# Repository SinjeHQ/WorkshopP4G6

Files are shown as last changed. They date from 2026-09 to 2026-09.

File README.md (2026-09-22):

# Sentinel — Sas de sécurité autonome du vaisseau

Projet réalisé pour le **Workshop National EPSI B3 — "Horizon 2080"** (septembre 2026), Pilier 4.

## L'idée en une phrase

On simule le sas d'entrée d'un vaisseau spatial qui doit rester sécurisé même quand il n'a plus aucun contact avec la Terre : un badge ouvre la porte, un capteur surveille qu'elle ne s'ouvre pas sans autorisation, et tout continue de fonctionner même si le réseau est coupé.

## Contexte du sujet

En 2080, l'ESA envoie des vaisseaux autonomes explorer l'espace lointain. Ces vaisseaux ne peuvent plus communiquer en temps réel avec la Terre, donc ils doivent savoir se protéger et fonctionner tout seuls. Notre projet répond à ça avec un système de sécurité physique complet.

## Composition de l'équipe

- **2 développeurs**
- **3 infra/réseau**

## Le projet est découpé en 4 parties

### 1. La partie IoT (l'objet physique)

C'est le cœur du projet : une carte électronique (ESP8266) qui pilote un mini "sas" physique.

- Un **lecteur de badge** identifie qui essaie de passer
- Une **porte motorisée** (petit servo-moteur) s'ouvre ou reste fermée selon le badge
- Un **capteur** surveille si la porte s'ouvre sans autorisation
- Une **alarme sonore et lumineuse** se déclenche en cas de problème

Quatre équipes du vaisseau ont chacune leur badge :

| Équipe | Accès au sas |
|---|---|
| Équipe Sécurité | ✅ Autorisé |
| Équipe Médicale | ✅ Autorisé |
| Équipe Énergétique | ❌ Refusé |
| Équipe Alimentaire | ❌ Refusé |

**Ce qui se passe concrètement :**
- Bon badge d'une équipe autorisée → petit bip, lumière verte, la porte s'ouvre puis se referme toute seule après 3 secondes
- Mauvais badge ou équipe non autorisée → lumière rouge, bip d'alerte
- Quelqu'un force la porte sans badge → alarme continue (son + lumière rouge clignotante) qui ne s'arrête que si un badge autorisé est présenté, peu importe si la porte est encore ouverte ou non

### 2. Le dashboard (l'écran de contrôle)

Une interface web qui permet de suivre en direct ce qui se passe sur le sas : qui est passé, quand, si une alarme a été déclenchée, et si le lien avec la Terre est actif ou coupé.

### 3. Le réseau sécurisé (la partie infra)

On simule le réseau interne du vaisseau avec plusieurs machines virtuelles :
- Une machine qui joue le rôle de **passerelle vers la Terre**, qu'on peut couper à volonté pour simuler une panne de communication
- Une machine qui fait tourner le réseau interne du vaisseau (réception des données du badge, surveillance, tableaux de bord)
- Un système qui **repère un comportement suspect** sur le réseau et isole automatiquement l'appareil concerné

L'objectif : montrer que même sans la Terre, le vaisseau continue à se défendre et à fonctionner tout seul.

### 4. La maquette 3D

Une représentation physique du sas (porte, cadre) sur laquelle sont fixés les composants électroniques (badge, capteur, moteur, alarme), pour rendre la démonstration concrète et visuelle devant le jury.

## Matériel utilisé (partie IoT)

| Composant | Rôle |
|---|---|
| ESP8266 (NodeMCU) | Cerveau électronique du système |
| Lecteur RFID RC522 | Lit les badges |
| Micro-servo SG90 | Ouvre/ferme la porte |
| Buzzer | Son d'alerte |
| Capteur magnétique | Détecte si la porte est ouverte ou fermée |
| LED rouge | Voyant d'alerte |
| LED verte | Voyant d'accès autorisé |

## Câblage

| Composant | Branché sur |
|---|---|
| Lecteur de badge | broches 3V, D3, G, D6, D7, D5, D8 |
| Moteur de la porte | broche D2 |
| Buzzer | broche D1 |
| Capteur de porte | broches 3V, G, A0 |
| Voyant rouge | broche D4 |
| Voyant vert | broche D0 |

**Attention alimentation** : pendant les tests, la carte doit être alimentée uniquement par le câble USB de l'ordinateur — jamais avec le bloc d'alimentation externe en même temps, pour ne pas l'endommager.

## Scénario de démonstration

1. On montre le fonctionnement normal : un badge autorisé ouvre la porte sans problème
2. On coupe volontairement le lien avec la Terre → le sas continue de fonctionner tout seul
3. On force la porte sans badge → l'alarme se déclenche immédiatement
4. On présente un badge autorisé → l'alarme s'arrête
5. On rétablit le lien avec la Terre → tout se resynchronise sur le dashboard

## Pistes d'amélioration pour une future version

- Garder un historique de tous les passages avec la date et l'heure
- Sécuriser davantage les échanges de données entre le sas et le dashboard
- Gérer plusieurs sas en même temps sur le même vaisseau

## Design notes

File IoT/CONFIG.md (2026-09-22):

# Initialiser `IoT.ino` avec Arduino IDE et NodeMCU 1.0

## Prérequis

- Installer Arduino IDE.
- Connecter la carte **NodeMCU 1.0 (ESP-12E Module)** au PC avec un câble USB permettant le transfert de données.
- Ouvrir le fichier `IoT.ino` dans Arduino IDE.

## Installer le support ESP8266

1. Ouvrir **Fichier > Préférences**.
2. Dans **URL de gestionnaire de cartes supplémentaires**, ajouter :
	`https://arduino.esp8266.com/stable/package_esp8266com_index.json`
3. Aller dans **Outils > Type de carte > Gestionnaire de cartes**.
4. Rechercher `ESP8266` et installer **esp8266 by ESP8266 Community**.

## Sélectionner la carte et le COM

1. Aller dans **Outils > Type de carte > ESP8266 Boards > NodeMCU 1.0 (ESP-12E Module)**.
2. Aller dans **Outils > Port** et sélectionner le port **COM** correspondant à la carte (par exemple `COM3`).
3. Si aucun port n’apparaît, installer le pilote USB adapté à la puce de la carte (CH340 ou CP210x), reconnecter la carte et redémarrer Arduino IDE.

## Téléverser le programme

1. Vérifier que le fichier principal s’appelle `IoT.ino` et que les éventuelles bibliothèques requises sont installées via **Outils > Gérer les bibliothèques**.
2. Cliquer sur **Vérifier** pour compiler.
3. Cliquer sur **Téléverser**.
4. Attendre le message **Téléversement terminé**. Si nécessaire, maintenir le bouton **FLASH** pendant le début du téléversement, puis le relâcher.
5. Ouvrir **Outils > Moniteur série** et sélectionner le débit indiqué dans le code (`Serial.begin(...)`).

Après chaque reconnexion, vérifier que le bon port COM est sélectionné avant de téléverser.

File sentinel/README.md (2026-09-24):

# Sentinel

Projet Workshop EPSI - Horizon 2080.

## Infrastructure

La V1 de l'infrastructure utilise :

- Debian Linux
- Docker
- Mosquitto MQTT
- Python
- PostgreSQL
- Grafana

## Architecture

```text
ESP8266
   |
   | MQTT
   v
Mosquitto
   |
   v
Python MQTT Listener
   |
   v
PostgreSQL
   |
   v
Grafana

<img width="1513" height="757" alt="SENTINEL_Architecture_V3 drawio" src="https://github.com/user-attachments/assets/c140471f-d6b1-40b4-9b26-e571d9b06512" />

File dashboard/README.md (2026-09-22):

# Sentinel — console du sas

Dashboard React du groupe 6, Workshop Horizon 2080.

Il affiche quatre choses, rafraîchies toutes les 3 secondes :

1. l'état du sas, d'après le dernier événement reçu ;
2. le lien avec la Terre : connecté ou mode autonome ;
3. l'historique des événements ;
4. les appareils du réseau de bord, rangés par VLAN, avec ceux qui sont isolés.

## Lancer le dashboard

1. `npm install` — une seule fois, pour installer les paquets.
2. Premier terminal : `npm run api` — la fausse API démarre sur http://localhost:3000
3. Second terminal : `npm run dev` — le dashboard s'ouvre sur http://localhost:5173

Les deux doivent tourner en même temps.

## Tester

Pendant que tout tourne, modifie `db.json` et enregistre : par exemple `"terre": "coupe"` devient `"terre": "connecte"`. Le dashboard change dans les 3 secondes.

## Brancher sur la VM

Dans `src/api.js`, remplacer `http://localhost:3000` par l'adresse de la VM Debian 12.

L'API de la VM doit fournir les trois fiches aux mêmes adresses que la fausse API : `/evenements`, `/statut` et `/appareils`.

## Les fichiers

- `src/api.js` : l'adresse de l'API, à un seul endroit.
- `src/App.jsx` : charge les trois fiches toutes les 3 secondes et les passe aux composants.
- `src/components/EtatSas.jsx` : l'état du sas.
- `src/components/StatutTerre.jsx` : le lien avec la Terre.
- `src/components/Historique.jsx` : la liste des événements.
- `src/components/Reseau.jsx` : les appareils par VLAN.
- `db.json` : les données de la fausse API.

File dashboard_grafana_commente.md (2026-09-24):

# Dashboard Grafana optimisé « Sentinel — Sécurité du SAS » — code commenté

## 1. Vue d'ensemble

Le fichier documenté est [`dashboard_grafana_optimise.json`](./dashboard_grafana_optimise.json), un dashboard Grafana au format JSON utilisant l'API `dashboard.grafana.app/v2`.

Cette documentation s'applique précisément à la version optimisée de 628 lignes. Cette version conserve les mêmes propriétés et les mêmes règles métier que le dashboard d'origine ; sa réduction vient du regroupement des petits objets JSON et de la mise en forme plus régulière du code.

> Le JSON standard n'accepte pas les commentaires. Les extraits ci-dessous utilisent donc `//` et `/* ... */` à des fins pédagogiques : ils ne doivent pas être importés tels quels dans Grafana. Le fichier JSON d'origine reste la version importable.

Tous les panels interrogent :

- la datasource PostgreSQL dont l'UID Grafana est `efz0jrz9r18g0d` ;
- le dataset/base déclaré `sentinel` ;
- la table `events` ;
- uniquement le dispositif `SAS-A01`.

Le schéma de données déduit des requêtes est :

| Colonne | Rôle |
|---|---|
| `device` | Identifiant de l'équipement, ici toujours `SAS-A01` |
| `event_type` | Famille de l'événement : `status`, `alarme`, `alarme_etat`, `porte`, `nfc`, etc. |
| `payload` | Valeur textuelle de l'événement : `offline`, `intrusion`, `ouverte`, `fermee`, `autorise`, `refuse`, etc. |
| `received_at` | Date et heure de réception de l'événement |

Chaîne générale de récupération et d'affichage :

```text
Équipement SAS-A01
  -> écrit des événements dans PostgreSQL / table events
  -> Grafana exécute la requête SQL du panel
  -> PostgreSQL renvoie une valeur, plusieurs champs ou une série temporelle
  -> Grafana applique les mappings, couleurs et options du panel
  -> le résultat apparaît dans le dashboard
```

Le dashboard affiche par défaut les 6 dernières heures :

```jsonc
"timeSettings": {
  "autoRefresh": "5s", // Grafana relance périodiquement les requêtes toutes les 5 secondes.
  "from": "now-6h",    // Début de la période affichée : maintenant moins 6 heures.
  "to": "now",         // Fin de la période : maintenant.
  "timezone": "browser" // Les dates sont affichées dans le fuseau du navigateur.
}
```

Attention : seuls les panels contenant `$__timeFilter(received_at)` suivent la période choisie dans le sélecteur de temps. Les panels utilisant seulement `ORDER BY received_at DESC LIMIT 1` cherchent le dernier événement de toute la table, indépendamment de cette période.

### Résumé de la récupération des données

| Panel | Donnée récupérée | Période Grafana | Affichage |
|---|---|---|---|
| NIVEAU DE SÉCURITÉ | Derniers états `status`, `alarme`, `porte` et dernier refus NFC | Non, sauf test interne de 10 secondes pour le refus | Statut coloré |
| État de la porte | Dernier événement `porte` | Non | Statut coloré |
| Dernier événement reçu | Dernière ligne de `events`, tous types confondus | Non | Libellé coloré |
| Dernier badge utilisé | Dernier événement `nfc` | Non | Autorisé/refusé |
| Badges acceptés | Nombre de badges autorisés | Oui | Compteur vert |
| Badges refusés | Nombre de badges refusés | Oui | Compteur orange |
| Anomalies de sécurité | Deux compteurs d'anomalies | Oui | Deux barres horizontales |
| Histogramme des événements | Comptage par minute et catégorie | Oui | Barres temporelles empilées |

## 2. Structure Grafana commune aux panels

Chaque panel possède cette structure logique :

```jsonc
"panel-XX": {                     // Identifiant interne du panel dans le dashboard.
  "kind": "Panel",               // L'élément est un panel Grafana.
  "spec": {
    "data": {
      "kind": "QueryGroup",      // Groupe des requêtes du panel.
      "spec": {
        "queries": [
          {
            "kind": "PanelQuery",
            "spec": {
              "hidden": false,    // La requête est active.
              "query": {
                "datasource": {
                  "name": "efz0jrz9r18g0d" // UID de la source PostgreSQL.
                },
                "group": "grafana-postgresql-datasource",
                "kind": "DataQuery",
                "spec": {
                  "dataset": "sentinel",
                  "editorMode": "code", // Requête écrite directement en SQL.
                  "format": "table",     // Ou `time_series` pour l'histogramme.
                  "rawQuery": true,
                  "rawSql": "..."        // SQL réellement envoyé à PostgreSQL.
                }
              },
              "refId": "A"        // Nom interne de la requête dans le panel.
            }
          }
        ],
        "transformations": []       // Aucune transformation Grafana après le SQL.
      }
    },
    "vizConfig": {
      "group": "stat",            // Type visuel : stat, bargauge ou timeseries.
      "spec": {
        "fieldConfig": { /* mappings, seuils, unités et couleurs */ },
        "options": { /* mode d'affichage du panel */ }
      }
    }
  }
}
```

Comme `transformations` est vide partout, les calculs métier sont faits directement par PostgreSQL. Grafana se charge surtout de convertir les valeurs numériques en textes/couleurs et de les dessiner.

## 3. Panel `panel-10` — NIVEAU DE SÉCURITÉ

### Requête SQL commentée

```sql
-- Récupère le tout dernier statut connu de l'équipement.
WITH last_status AS (
    SELECT
        lower(COALESCE(payload, '')) AS payload, -- NULL devient '', puis le texte passe en minuscules.
        received_at
    FROM events
    WHERE device = 'SAS-A01'
      AND event_type = 'status'
    ORDER BY received_at DESC -- Le plus récent en premier.
    LIMIT 1                   -- Uniquement le dernier statut.
),

-- Récupère le dernier événement lié à l'état de l'alarme.
last_alarm AS (
    SELECT
        event_type,
        lower(COALESCE(payload, '')) AS payload,
        received_at
    FROM events
    WHERE device = 'SAS-A01'
      AND event_type IN ('alarme', 'alarme_etat')
    ORDER BY received_at DESC
    LIMIT 1
),

-- Récupère le dernier état connu de la porte.
last_door AS (
    SELECT
        lower(COALESCE(payload, '')) AS payload,
        received_at
    FROM events
    WHERE device = 'SAS-A01'
      AND event_type = 'porte'
    ORDER BY received_at DESC
    LIMIT 1
),

-- Récupère le dernier refus de badge, quelle que soit son ancienneté.
last_refused AS (
    SELECT received_at
    FROM events
    WHERE device = 'SAS-A01'
      AND event_type = 'nfc'
      AND lower(COALESCE(payload, '')) IN ('refuse', 'refusé')
    ORDER BY received_at DESC
    LIMIT 1
)

-- Convertit l'état global en un code numérique compris entre 0 et 3.
SELECT CASE
    -- Priorité 1 : aucun statut trouvé ou dernier statut explicitement `offline`.
    WHEN NOT EXISTS (SELECT 1 FROM last_status) THEN 3
    WHEN (SELECT payload FROM last_status) = 'offline' THEN 3

    -- Priorité 2 : le dernier événement d'alarme est une intrusion active.
    WHEN EXISTS (
        SELECT 1
        FROM last_alarm
        WHERE event_type = 'alarme'
          AND payload = 'intrusion'
    ) THEN 2

    -- Priorité 3 : la dernière information de porte dit qu'elle est ouverte.
    WHEN EXISTS (
        SELECT 1
        FROM last_door
        WHERE payload = 'ouverte'
    ) THEN 1

    -- Priorité 4 : un badge a été refusé dans les 10 dernières secondes.
    WHEN EXISTS (
        SELECT 1
        FROM last_refused
        WHERE received_at > now() - interval '10 seconds'
    ) THEN 1

    -- Sinon, l'installation est considérée comme sécurisée.
    ELSE 0
END::double precision AS "État global";
```

### Passage de la donnée à l'écran

La requête renvoie un seul nombre. Grafana applique le mapping suivant :

| Valeur SQL | Texte affiché | Couleur |
|---:|---|---|
| `0` | `SÉCURISÉ` | vert |
| `1` | `ALERTE` | jaune |
| `2` | `INTRUSION` | rouge |
| `3` | `HORS LIGNE` | gris |

Le mode `colorMode: background` colore tout le fond. `lastNotNull` demande à Grafana d'afficher la dernière valeur non nulle reçue.

La priorité est importante : hors ligne l'emporte sur intrusion, qui l'emporte sur porte ouverte, qui l'emporte sur badge refusé récent.

## 4. Panel `panel-24` — État de la porte

```sql
SELECT CASE lower(payload)
    WHEN 'ouverte' THEN 1 -- Dernier payload = ouverte.
    WHEN 'fermee'  THEN 0 -- Dernier payload = fermee, sans accent dans les données.
    ELSE -1               -- Toute autre valeur est considérée inconnue.
END::double precision AS "Porte"
FROM events
WHERE device = 'SAS-A01'
  AND event_type = 'porte'       -- Ignore tous les événements non liés à la porte.
ORDER BY received_at DESC        -- Cherche le plus récent dans toute la table.
LIMIT 1;
```

| Valeur SQL | Texte affiché | Couleur configurée |
|---:|---|---|
| `-1` | `INCONNUE` | gris |
| `0` | `FERMÉE` | rouge |
| `1` | `OUVERTE` | vert |

Ce panel ne dépend pas du sélecteur temporel. S'il n'existe aucune ligne `porte`, PostgreSQL renvoie zéro ligne et Grafana affiche généralement « No data », pas la valeur `-1`.

## 5. Panel `panel-12` — Dernier événement reçu

```sql
SELECT CASE
    WHEN event_type = 'alarme' AND lower(payload) = 'intrusion' THEN 5
    WHEN event_type = 'status' AND lower(payload) = 'offline' THEN 4
    WHEN event_type = 'nfc' AND lower(payload) IN ('refuse', 'refusé') THEN 3
    WHEN event_type = 'nfc' AND lower(payload) IN ('autorise', 'accepte') THEN 2
    WHEN event_type = 'porte' AND lower(payload) = 'ouverte' THEN 1
    WHEN event_type = 'porte' AND lower(payload) = 'fermee' THEN 0
    ELSE 6 -- Tout couple type/payload non reconnu devient « autre événement ».
END::double precision AS "Dernier événement"
FROM events
WHERE device = 'SAS-A01'
ORDER BY received_at DESC -- Dernier événement du dispositif, tous types confondus.
LIMIT 1;
```

| Valeur SQL | Texte affiché | Couleur |
|---:|---|---|
| `0` | `PORTE FERMÉE` | rouge |
| `1` | `PORTE OUVERTE` | vert |
| `2` | `BADGE AUTORISÉ` | vert |
| `3` | `BADGE REFUSÉ` | orange |
| `4` | `SUPERVISION HORS LIGNE` | gris |
| `5` | `INTRUSION` | rouge |
| `6` | `AUTRE ÉVÉNEMENT` | bleu |

La description du panel annonce « Type, valeur et heure du dernier message », mais la requête ne renvoie que le code du type/valeur. Elle ne sélectionne pas `received_at` : l'heure n'est donc pas affichée par ce code.

## 6. Panel `panel-13` — Dernier badge utilisé

```sql
SELECT CASE
    WHEN lower(payload) IN ('autorise', 'accepte') THEN 1
    WHEN lower(payload) IN ('refuse', 'refusé') THEN 0
    ELSE -1
END::double precision AS "Dernier badge"
FROM events
WHERE device = 'SAS-A01'
  AND event_type = 'nfc'  -- Ne conserve que les passages de badge.
ORDER BY received_at DESC
LIMIT 1;                  -- Dernière décision NFC de toute la table.
```

| Valeur SQL | Texte affiché | Couleur |
|---:|---|---|
| `-1` | `INCONNU` | gris |
| `0` | `REFUSÉ` | rouge |
| `1` | `AUTORISÉ` | vert |

Le panel est indépendant de la période Grafana. Comme pour la porte, l'absence totale d'événement NFC produit zéro ligne et non `-1`.

## 7. Panel `panel-15` — Badges acceptés

```sql
SELECT
    COUNT(*)::double precision AS "Badges acceptés" -- Compte les lignes correspondantes.
FROM events
WHERE device = 'SAS-A01'
  AND event_type = 'nfc'
  AND lower(payload) IN ('autorise', 'accepte')
  AND $__timeFilter(received_at); -- Macro Grafana remplacée par les bornes de temps choisies.
```

`$__timeFilter(received_at)` devient approximativement une condition du type :

```sql
received_at BETWEEN 'date_de_début' AND 'date_de_fin'
```

Le résultat est un compteur unique. Le panel `stat` l'affiche sur un fond vert fixe. Il se recalcule au rafraîchissement et change lorsque l'utilisateur modifie la période.

## 8. Panel `panel-16` — Badges refusés

```sql
SELECT
    COUNT(*)::double precision AS "Badges refusés"
FROM events
WHERE device = 'SAS-A01'
  AND event_type = 'nfc'
  AND lower(payload) IN ('refuse', 'refusé')
  AND $__timeFilter(received_at);
```

Le fonctionnement est identique au panel précédent, mais il compte les refus. Le fond est orange fixe.

## 9. Panel `panel-14` — Anomalies de sécurité

```sql
SELECT
  -- Premier compteur : intrusion, type « porte forcée » ou payload « forcée ».
  COUNT(*) FILTER (
    WHERE event_type = 'alarme' AND lower(payload) = 'intrusion'
       OR event_type IN ('porte_forcee', 'porte-forcée')
       OR lower(payload) IN ('forcee', 'forcée')
  )::double precision AS "Porte forcée / intrusion",

  -- Deuxième compteur : refus NFC.
  COUNT(*) FILTER (
    WHERE event_type = 'nfc'
      AND lower(payload) IN ('refuse', 'refusé')
  )::double precision AS "Mauvais badge"
FROM events
WHERE device = 'SAS-A01'
  AND $__timeFilter(received_at); -- Les deux compteurs suivent la période Grafana.
```

PostgreSQL renvoie une seule ligne avec deux colonnes. Le `Bar gauge` les transforme en deux barres horizontales :

- `Porte forcée / intrusion`, forcée en rouge par un override ;
- `Mauvais badge`, forcée en orange.

Il n'existe pas de transformation Grafana : les deux agrégations proviennent directement des deux `COUNT(*) FILTER (...)` SQL.

## 10. Panel `panel-28` — Histogramme des événements

```sql
SELECT
  -- Macro Grafana : arrondit received_at par intervalles d'une minute
  -- et donne à cette colonne l'alias temporel attendu par Grafana.
  $__timeGroupAlias(received_at, '1m'),

  -- Transforme chaque événement en nom de série.
  CASE
    WHEN event_type = 'nfc' AND lower(payload) IN ('autorise', 'accepte')
      THEN 'Badge autorisé'
    WHEN event_type = 'nfc' AND lower(payload) IN ('refuse', 'refusé')
      THEN 'Mauvais badge'
    WHEN event_type = 'porte' AND lower(payload) = 'ouverte'
      THEN 'Porte ouverte'
    WHEN event_type = 'porte' AND lower(payload) = 'fermee'
      THEN 'Porte fermée'
    WHEN event_type = 'alarme' AND lower(payload) = 'intrusion'
      THEN 'Porte forcée / intrusion'
    ELSE 'Autre événement'
  END AS metric,

  -- Nombre d'événements dans chaque couple minute/catégorie.
  COUNT(*)::double precision AS value
FROM events
WHERE device = 'SAS-A01'
  AND event_type IN ('nfc', 'porte', 'alarme', 'porte_forcee', 'porte-forcée')
  AND $__timeFilter(received_at)
GROUP BY 1, 2 -- Groupe par minute puis par libellé `metric`.
ORDER BY 1;   -- Trie les points chronologiquement.
```

La requête est déclarée avec `format: time_series`. Grafana reçoit donc, pour chaque ligne :

1. une date arrondie à la minute ;
2. un nom de série dans `metric` ;
3. un nombre dans `value`.

Le panel dessine des barres empilées (`drawStyle: bars`, `stacking.mode: normal`) et leur affecte ces couleurs :

| Série | Couleur |
|---|---|
| Badge autorisé | vert |
| Mauvais badge | orange |
| Porte ouverte | bleu |
| Porte fermée | violet |
| Porte forcée / intrusion | rouge |
| Autre événement | palette automatique |

La légende affiche aussi la somme de chaque série sur la période (`legend.calcs: ["sum"]`).

## 11. Disposition du dashboard

La grille Grafana fait 24 colonnes. Les coordonnées `x`, `y`, `width` et `height` ne changent pas les données : elles déterminent seulement la position et la taille des panels.

```text
Ligne 1 : [Niveau sécurité 8] [État porte 4] [Dernier événement 6] [Dernier badge 6]
Ligne 2 : [Badges acceptés 6] [Anomalies 12] [Badges refusés 6]
Ligne 3 : [Histogramme 24]
```

## 12. Points d'attention relevés

1. **Pas de gestion de vieillissement du statut.** `NIVEAU DE SÉCURITÉ` considère l'équipement en ligne tant que le dernier payload `status` n'est pas `offline`, même si cet événement date de longtemps. Il n'y a pas de test du type `received_at < now() - interval ...`.

2. **L'heure promise n'est pas affichée.** Le panel `Dernier événement reçu` ne sélectionne pas `received_at`, contrairement à sa description.

3. **Absence de données différente de valeur inconnue.** Dans `État de la porte` et `Dernier badge utilisé`, le `ELSE -1` ne s'applique que si une ligne existe avec un payload inattendu. S'il n'existe aucune ligne, la requête ne renvoie rien.

4. **Classification partielle des portes forcées dans l'histogramme.** Le `WHERE` accepte `porte_forcee` et `porte-forcée`, mais le `CASE` ne les classe pas explicitement comme `Porte forcée / intrusion`. Ces événements tombent dans `Autre événement`, sauf si une autre condition correspond.

5. **Couleurs porte potentiellement contre-intuitives.** Les panels configurent `FERMÉE` en rouge et `OUVERTE` en vert. Pour un dashboard de sécurité, l'inverse pourrait être attendu ; il faut confirmer le sens métier voulu.

6. **Orthographes normalisées seulement en partie.** `lower(...)` neutralise les majuscules/minuscules, mais pas les accents ni les variantes de mots. Par exemple `fermee` est reconnu, tandis que `fermée` ne l'est pas dans les requêtes actuelles.

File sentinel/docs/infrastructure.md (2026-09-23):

SENTINEL — Infrastructure V1
1. Objectif de l’infrastructure

L’objectif de l’infrastructure Sentinel est de fournir une plateforme locale capable de :

recevoir les événements générés par les équipements Sentinel ;
transporter les événements via MQTT ;
traiter les données reçues ;
conserver un historique des événements ;
afficher les données dans un dashboard de supervision ;
continuer à superviser le système sans dépendre d’une connexion Internet ;
permettre par la suite l’ajout de fonctions de cybersécurité : IDS, détection de scans réseau, authentification MQTT, firewall, alertes, etc.

L’infrastructure a été pensée pour séparer le fonctionnement physique critique du SAS et la supervision.

Le SAS doit donc pouvoir continuer à fonctionner localement même si l’infrastructure de supervision devient indisponible.

2. Architecture générale
                     SENTINEL V1

                ÉQUIPEMENT / ESP8266
                        │
                        │
                  Wi-Fi + MQTT
                        │
                        ▼
                ┌───────────────┐
                │   Mosquitto   │
                │ Broker MQTT   │
                │   TCP 1883    │
                └───────┬───────┘
                        │
                        │ sentinel/#
                        ▼
                ┌───────────────┐
                │ Python        │
                │ MQTT Listener │
                └───────┬───────┘
                        │
                     SQL INSERT
                        │
                        ▼
                ┌───────────────┐
                │ PostgreSQL    │
                │ Base Sentinel │
                └───────┬───────┘
                        │
                   Requêtes SQL
                        │
                        ▼
                ┌───────────────┐
                │    Grafana    │
                │   Dashboard   │
                └───────────────┘

La partie centrale est hébergée sur une VM Debian.

3. Technologies utilisées
Technologie	Utilisation	Pourquoi
Debian Linux	Système serveur	Léger, stable, adapté à l’administration système
VMware Workstation	Hébergement de la VM	Permet d’isoler l’infrastructure du poste Windows
Docker	Conteneurisation	Déploiement simple et séparation des services
Docker Compose	Orchestration	Permet de lancer toute l’infrastructure avec un seul fichier
Eclipse Mosquitto	Broker MQTT	Léger et adapté aux communications IoT
MQTT	Transport des événements	Protocole léger, asynchrone et adapté à l’IoT
Python	Traitement des événements	Simple à intégrer avec MQTT et PostgreSQL
Paho MQTT	Client MQTT Python	Permet à Python de recevoir les messages Mosquitto
Psycopg	Connexion PostgreSQL	Permet à Python d’insérer les événements dans la base
PostgreSQL 16	Base de données	Stockage durable et structuré des événements
Grafana	Supervision	Création rapide de dashboards à partir de PostgreSQL
systemd	Automatisation	Prévu pour démarrer automatiquement le listener Python
4. Environnement serveur

Le serveur Sentinel fonctionne sous :

Debian Linux

virtualisé avec :

VMware Workstation

Le projet est installé dans :

/home/benjamin/sentinel

Arborescence actuelle :

sentinel/
│
├── backend/
│   ├── mqtt_listener.py
│   └── venv/
│
├── mosquitto/
│   └── config/
│       └── mosquitto.conf
│
└── docker-compose.yml
5. Configuration réseau

La VM utilise l’interface :

ens33

La VM a d’abord été utilisée en NAT VMware.

Pour permettre à l’ESP8266 et aux autres machines du réseau de joindre directement Mosquitto, le réseau VMware a ensuite été passé en :

Bridged / VMnet0

La VM obtient actuellement son adresse via DHCP.

Configuration Debian :

sudo nano /etc/network/interfaces

Configuration :

source /etc/network/interfaces.d/*

auto lo
iface lo inet loopback

allow-hotplug ens33
iface ens33 inet dhcp

Vérification de l’adresse :

ip addr show ens33

Vérification de la route :

ip route
6. Point de blocage : adresse IP dynamique

Un problème rencontré concerne le DHCP.

L’adresse IP de la VM peut changer après un changement de réseau ou un redémarrage.

Exemple :

10.240.140.182

puis potentiellement :

10.240.140.xxx

Cela pose un problème car les clients MQTT utilisent actuellement directement l’adresse IP du broker.

Conséquences :

IP VM change
   │
   ├── adresse MQTT à modifier côté client
   ├── URL Grafana différente
   └── connexion SSH différente

Solution actuelle :

ip addr show ens33

avant de vérifier la configuration MQTT.

Évolution prévue :

réservation DHCP ;
IP fixe ;
ou résolution du broker par nom DNS/mDNS.
7. Docker

Docker permet de faire fonctionner séparément les différents services.

Services actuellement conteneurisés :

sentinel-mqtt
sentinel-db
sentinel-grafana

Vérification :

docker ps

Architecture :

Docker
│
├── sentinel-mqtt
│      └── Eclipse Mosquitto
│
├── sentinel-db
│      └── PostgreSQL 16
│
└── sentinel-grafana
       └── Grafana
8. Docker Compose

Fichier :

/home/benjamin/sentinel/docker-compose.yml

Configuration utilisée pendant la V1 :

services:

  mosquitto:
    image: eclipse-mosquitto
    container_name: sentinel-mqtt
    restart: unless-stopped

    ports:
      - "1883:1883"

    volumes:
      - ./mosquitto/config/mosquitto.conf:/mosquitto/config/mosquitto.conf

  postgres:
    image: postgres:16
    container_name: sentinel-db
    restart: unless-stopped

    environment:
      POSTGRES_USER: sentinel
      POSTGRES_PASSWORD: sentinel
      POSTGRES_DB: sentinel

    ports:
      - "127.0.0.1:5432:5432"

    volumes:
      - postgres_data:/var/lib/postgresql/data

  grafana:
    image: grafana/grafana
    container_name: sentinel-grafana
    restart: unless-stopped

    ports:
      - "3000:3000"

volumes:
  postgres_data:

Lancement :

cd /home/benjamin/sentinel
docker compose up -d

Arrêt :

docker compose down

Redémarrage :

docker compose restart

Vérification :

docker ps
9. Persistance des données PostgreSQL

Un volume Docker est utilisé :

volumes:
  postgres_data:

Puis :

- postgres_data:/var/lib/postgresql/data

Cela permet de conserver les données PostgreSQL même si le conteneur est recréé.

10. Mosquitto

Mosquitto joue le rôle de broker MQTT.

Il ne stocke pas les données métier dans PostgreSQL lui-même.

Son rôle est :

Publisher
   ↓
Mosquitto
   ↓
Subscribers

Dans Sentinel :

Équipement
   ↓
Mosquitto
   ↓
mqtt_listener.py

Configuration :

/home/benjamin/sentinel/mosquitto/config/mosquitto.conf

V1 :

listener 1883
allow_anonymous true

Port :

1883/TCP
11. Pourquoi MQTT ?

MQTT a été choisi car il correspond bien à une architecture IoT.

Il permet :

publication asynchrone ;
faible consommation réseau ;
découplage entre l’équipement et les applications ;
architecture publisher/subscriber ;
utilisation de topics hiérarchiques ;
fonctionnement sur un réseau local.

L’équipement n’a donc pas besoin de connaître PostgreSQL ou Grafana.

Il connaît uniquement :

Broker MQTT
12. Convention des topics

Structure retenue :

sentinel/sas/<ID>/<TYPE>

Exemple pour SAS-A01 :

sentinel/sas/A01/status
sentinel/sas/A01/porte
sentinel/sas/A01/nfc
sentinel/sas/A01/equipe
sentinel/sas/A01/alarme
sentinel/sas/A01/alarme_etat
sentinel/sas/A01/presence

Exemple :

sentinel/sas/A01/nfc autorise

ou :

sentinel/sas/A01/porte ouverte
13. Wildcard MQTT

Le listener Python utilise :

sentinel/#

Le caractère :

#

indique :

écouter tous les sous-topics commençant par sentinel/.

Ainsi le listener peut recevoir tous les événements actuels et futurs.

14. Test Mosquitto

Pour observer les messages MQTT :

mosquitto_sub \
-h 127.0.0.1 \
-p 1883 \
-t "sentinel/#" \
-v

Exemple obtenu :

sentinel/sas/A01/nfc autorise

Test de publication :

mosquitto_pub \
-h 127.0.0.1 \
-p 1883 \
-t "sentinel/sas/A01/nfc" \
-m "autorise"

Ces commandes sont des outils de diagnostic uniquement.

Elles ne sont pas nécessaires en fonctionnement normal.

15. PostgreSQL

PostgreSQL permet de stocker durablement les événements.

Configuration :

Database : sentinel
User     : sentinel
Port     : 5432

Le port a été volontairement exposé uniquement sur localhost :

ports:
  - "127.0.0.1:5432:5432"

Cela signifie qu’une autre machine du réseau ne peut pas directement se connecter à PostgreSQL via le port 5432 de la VM.

16. Table events

Table utilisée :

CREATE TABLE events (
    id BIGSERIAL PRIMARY KEY,
    received_at TIMESTAMPTZ NOT NULL DEFAULT NOW(),
    device VARCHAR(100) NOT NULL,
    topic VARCHAR(255) NOT NULL,
    event_type VARCHAR(100) NOT NULL,
    payload TEXT,
    severity VARCHAR(20) NOT NULL DEFAULT 'info'
);

Exemple de données :

id          25
device      SAS-A01
event_type  nfc
payload     autorise
severity    info

Ou :

device      SAS-A01
event_type  alarme
payload     intrusion
severity    critical
17. Consultation de PostgreSQL

Connexion :

docker exec -it sentinel-db \
psql -U sentinel -d sentinel

Lecture :

SELECT *
FROM events
ORDER BY received_at DESC;

Ou directement :

docker exec -it sentinel-db \
psql -U sentinel -d sentinel \
-c "SELECT id, received_at, device, event_type, payload, severity FROM events ORDER BY id DESC LIMIT 20;"
18. Backend Python

Un programme Python fait le lien entre MQTT et PostgreSQL.

Architecture :

Mosquitto
   ↓
Paho MQTT
   ↓
mqtt_listener.py
   ↓
Psycopg
   ↓
PostgreSQL

Répertoire :

/home/benjamin/sentinel/backend
19. Environnement virtuel Python

Création :

cd /home/benjamin/sentinel/backend
python3 -m venv venv

Activation :

source venv/bin/activate

Installation :

pip install paho-mqtt "psycopg[binary]"

Dépendances :

paho-mqtt
psycopg[binary]

Pour GitHub, création recommandée de :

requirements.txt

avec :

paho-mqtt
psycopg[binary]

Puis installation :

pip install -r requirements.txt
20. mqtt_listener.py

Le listener :

se connecte à Mosquitto ;
s’abonne à sentinel/# ;
reçoit les messages ;
détermine le type d’événement ;
attribue une sévérité ;
insère l’événement dans PostgreSQL.

Version utilisée :

import paho.mqtt.client as mqtt
import psycopg
from datetime import datetime

MQTT_HOST = "127.0.0.1"
MQTT_PORT = 1883

MQTT_TOPIC = "sentinel/#"

DEVICE_NAME = "SAS-A01"

DB_HOST = "127.0.0.1"
DB_PORT = 5432

DB_NAME = "sentinel"
DB_USER = "sentinel"
DB_PASSWORD = "sentinel"

def enregistrer_evenement(topic, message):

    event_type = topic.split("/")[-1]

    severity = "info"

    if event_type == "alarme":
        severity = "critical"

    elif event_type == "nfc" and message == "refuse":
        severity = "warning"

    try:

        with psycopg.connect(
            host=DB_HOST,
            port=DB_PORT,
            dbname=DB_NAME,
            user=DB_USER,
            password=DB_PASSWORD
        ) as conn:

            with conn.cursor() as cur:

                cur.execute(
                    """
                    INSERT INTO events
                    (
                        device,
                        topic,
                        event_type,
                        payload,
                        severity
                    )
                    VALUES
                    (
                        %s,
                        %s,
                        %s,
                        %s,
                        %s
                    )
                    """,
                    (
                        DEVICE_NAME,
                        topic,
                        event_type,
                        message,
                        severity
                    )
                )

                conn.commit()

        print("[DB] Evenement enregistre")

    except Exception as e:

        print("[DB] Erreur :", e)

def on_connect(client, userdata, flags, reason_code, properties):

    print("[MQTT] Connecte a Mosquitto")
    print("[MQTT] Ecoute :", MQTT_TOPIC)

    client.subscribe(MQTT_TOPIC)

def on_message(client, userdata, msg):

    message = msg.payload.decode()

    print("------------------------------")
    print("Date    :", datetime.now())
    print("Topic   :", msg.topic)
    print("Message :", message)

    enregistrer_evenement(
        msg.topic,
        message
    )

print("Connexion a Mosquitto...")

print("==============================")
print(" SENTINEL - MQTT LISTENER")
print("==============================")

client = mqtt.Client(
    mqtt.CallbackAPIVersion.VERSION2
)

client.on_connect = on_connect
client.on_message = on_message

client.connect(
    MQTT_HOST,
    MQTT_PORT,
    60
)

client.loop_forever()
21. Gestion des sévérités

Logique actuelle :

Événement classique
→ info

Accès NFC refusé
→ warning

Intrusion
→ critical

Python :

severity = "info"

if event_type == "alarme":
    severity = "critical"

elif event_type == "nfc" and message == "refuse":
    severity = "warning"
22. Lancement du listener

Actuellement, lancement manuel :

cd /home/benjamin/sentinel/backend
source venv/bin/activate
python mqtt_listener.py

Résultat :

Connexion a Mosquitto...

==============================
 SENTINEL - MQTT LISTENER
==============================

[MQTT] Connecte a Mosquitto
[MQTT] Ecoute : sentinel/#

Le programme reste volontairement lancé en permanence car il attend les événements MQTT.

23. Automatisation systemd

Cette partie est prévue / en cours de mise en place.

Objectif :

VM démarre
   ↓
listener démarre automatiquement

Service prévu :

/etc/systemd/system/sentinel-listener.service

Configuration :

[Unit]
Description=Sentinel MQTT Listener
Wants=network-online.target
After=network-online.target docker.service

[Service]
Type=simple
User=benjamin
WorkingDirectory=/home/benjamin/sentinel/backend
ExecStart=/home/benjamin/sentinel/backend/venv/bin/python /home/benjamin/sentinel/backend/mqtt_listener.py

Restart=always
RestartSec=5
Environment=PYTHONUNBUFFERED=1

[Install]
WantedBy=multi-user.target

Activation :

sudo systemctl daemon-reload
sudo systemctl enable sentinel-listener
sudo systemctl start sentinel-listener

Vérification :

sudo systemctl status sentinel-listener

Logs :

journalctl -u sentinel-listener -f

Cette étape doit être validée avant de la considérer comme terminée dans le projet.

24. Grafana

Grafana permet de créer le dashboard de supervision.

Accès :

http://IP_VM:3000

Exemple :

http://10.240.140.182:3000

L’adresse dépend actuellement du DHCP.

25. Connexion Grafana → PostgreSQL

Datasource :

PostgreSQL

Configuration :

Host :
postgres:5432

Database :
sentinel

User :
sentinel

Password :
sentinel

TLS :
Disabled

Pourquoi :

postgres:5432

et pas :

127.0.0.1:5432

Parce que Grafana et PostgreSQL sont deux conteneurs différents.

Docker Compose crée un réseau interne où le service PostgreSQL est accessible via son nom :

postgres
26. Dashboard Grafana
Historique
SELECT
    received_at AS "Heure",
    device AS "SAS",
    event_type AS "Type",
    payload AS "Valeur",
    severity AS "Niveau"
FROM events
WHERE device = 'SAS-A01'
ORDER BY received_at DESC
LIMIT 50;
27. État de la porte
SELECT
    CASE
        WHEN payload = 'ouverte' THEN 'OUVERTE'
        WHEN payload = 'fermee' THEN 'FERMEE'
        ELSE UPPER(payload)
    END AS "Porte"
FROM events
WHERE device = 'SAS-A01'
AND event_type = 'porte'
ORDER BY received_at DESC
LIMIT 1;
28. Dernier badge
SELECT
    CASE
        WHEN payload = 'autorise' THEN 'AUTORISE'
        WHEN payload = 'refuse' THEN 'REFUSE'
        ELSE UPPER(payload)
    END AS "Badge"
FROM events
WHERE device = 'SAS-A01'
AND event_type = 'nfc'
ORDER BY received_at DESC
LIMIT 1;
29. Dernière équipe
SELECT
    payload AS "Equipe"
FROM events
WHERE device = 'SAS-A01'
AND event_type = 'equipe'
ORDER BY received_at DESC
LIMIT 1;
30. Intrusions
SELECT
    COUNT(*) AS "Intrusions"
FROM events
WHERE device = 'SAS-A01'
AND event_type = 'alarme'
AND payload = 'intrusion';
31. Accès refusés
SELECT
    COUNT(*) AS "Acces refuses"
FROM events
WHERE device = 'SAS-A01'
AND event_type = 'nfc'
AND payload = 'refuse';
32. Activité
SELECT
    date_trunc('minute', received_at) AS "time",
    COUNT(*) AS "Evenements"
FROM events
WHERE device = 'SAS-A01'
GROUP BY date_trunc('minute', received_at)
ORDER BY "time";
33. Actualisation Grafana

Le dashboard a été configuré avec :

Refresh : 5 secondes

Avant cette configuration, les événements apparaissaient bien dans PostgreSQL mais le dashboard Grafana ne se rafraîchissait pas automatiquement.

Ce problème a été corrigé en activant l’auto-refresh.

34. Flux complet validé

La chaîne suivante a été validée :

Événement
   ↓
MQTT
   ↓
Mosquitto
   ↓
mqtt_listener.py
   ↓
PostgreSQL
   ↓
Grafana

Exemple réel :

Topic :
sentinel/sas/A01/nfc

Payload :
autorise

Réception Python :

Date    : 2026-09-22 15:26:26
Topic   : sentinel/sas/A01/nfc
Message : autorise

[DB] Evenement enregistre

Le même événement a été observé simultanément via :

mosquitto_sub

et dans le listener Python.

35. Points de blocage rencontrés
Adresse IP dynamique

Problème :

La VM est en DHCP, donc son IP peut changer.

Impact :

connexion MQTT externe ;
Grafana ;
SSH.

Solution temporaire :

ip addr show ens33

Évolution :

IP fixe / DHCP reservation / DNS
Mosquitto non accessible depuis l’extérieur

Au début, la VM était derrière le NAT VMware.

Cela rendait la communication directe avec les équipements externes plus compliquée.

Solution :

VMware Bridged Network
Configuration Mosquitto

Mosquitto ne permettait pas immédiatement les connexions externes.

Pour la V1 :

listener 1883
allow_anonymous true

Cela simplifie la démonstration, mais ce n’est pas une configuration cible de production.

Listener Python bloqué dans le terminal

Lors du lancement :

python mqtt_listener.py

la commande ne rend pas la main.

Ce n’est pas un bug.

Le listener utilise :

client.loop_forever()

et doit rester actif pour recevoir les événements.

Solution cible :

service systemd
Plusieurs terminaux lors des tests

Durant le diagnostic, trois terminaux étaient parfois utilisés :

Terminal 1
mqtt_listener.py

Terminal 2
mosquitto_sub

Terminal 3
mosquitto_pub

Ils servaient uniquement aux tests.

En fonctionnement normal :

mosquitto_sub

et :

mosquitto_pub

ne sont pas nécessaires.

Grafana non actualisé automatiquement

Les données arrivaient correctement dans PostgreSQL mais le dashboard ne changeait qu’après rafraîchissement manuel.

Solution :

Grafana Auto Refresh = 5s
Connexion PostgreSQL depuis Grafana

La première difficulté était de comprendre que :

localhost

dans le conteneur Grafana désigne Grafana lui-même.

Solution :

postgres:5432

grâce au réseau Docker Compose.

36. État actuel de la V1

Fonctionnel :

✅ Debian
✅ VMware bridged network
✅ Docker
✅ Docker Compose
✅ Mosquitto
✅ MQTT
✅ PostgreSQL
✅ Persistance PostgreSQL
✅ Listener Python
✅ Paho MQTT
✅ Psycopg
✅ Historisation des événements
✅ Gestion des niveaux info / warning / critical
✅ Grafana
✅ Dashboard
✅ Rafraîchissement automatique
✅ Tests MQTT mosquitto_pub / mosquitto_sub

À finaliser :

⬜ Automatisation complète via systemd
⬜ Stabilisation de l'adresse IP
⬜ Gestion des secrets
37. Sécurité actuelle

Quelques mesures sont déjà présentes.

PostgreSQL n’est exposé que sur localhost :

127.0.0.1:5432

Les différents services sont séparés dans leurs conteneurs.

Les données PostgreSQL sont persistantes.

Le backend Python est séparé des conteneurs.

38. Limites de sécurité de la V1

Mosquitto utilise encore :

allow_anonymous true

Les communications MQTT ne sont pas chiffrées.

Les identifiants PostgreSQL apparaissent encore dans les fichiers.

Il n’y a pas encore :

ACL MQTT
TLS
Firewall configuré spécifiquement
IDS
IPS
Détection de scans
Gestion centralisée des secrets
39. GitHub — ne pas publier les secrets

Avant publication publique, les mots de passe doivent être retirés du code.

Exemple Docker :

environment:
  POSTGRES_USER: ${POSTGRES_USER}
  POSTGRES_PASSWORD: ${POSTGRES_PASSWORD}
  POSTGRES_DB: ${POSTGRES_DB}

Créer :

.env.example
POSTGRES_USER=sentinel
POSTGRES_PASSWORD=CHANGE_ME
POSTGRES_DB=sentinel

Et :

.gitignore
.env
venv/
__pycache__/
*.pyc
.vscode/
.idea/

Le fichier réel :

.env

ne doit pas être poussé sur GitHub.

40. Améliorations prévues

La V2 doit renforcer la partie administration système / cybersécurité.

Évolutions envisagées :

Authentification Mosquitto
↓
ACL MQTT
↓
MQTT TLS
↓
Firewall Debian
↓
Suricata IDS
↓
Détection de scans Nmap
↓
Logs cyber
↓
PostgreSQL
↓
Grafana
41. Détection réseau prévue

Un des objectifs suivants est de détecter une activité comme :

Scan Nmap

Architecture cible :

Machine de test
      │
      │ scan
      ▼
Debian
      │
      ▼
Suricata IDS
      │
      ▼
Alerte cyber
      │
      ▼
PostgreSQL
      │
      ▼
Grafana

Cela permettra de réunir dans un même dashboard :

Supervision opérationnelle
+
Supervision cybersécurité
42. Architecture cible V2
                       SENTINEL V2

                           │
                           ▼
                       Mosquitto
                           │
                 ┌─────────┴─────────┐
                 │                   │
                 ▼                   ▼
          MQTT Listener          Suricata IDS
                 │                   │
                 │                   │
                 └─────────┬─────────┘
                           │
                           ▼
                      PostgreSQL
                           │
                           ▼
                        Grafana
                           │
             ┌─────────────┴─────────────┐
             │                           │
             ▼                           ▼
     Supervision système          Cybersécurité
43. Résumé du fonctionnement

La V1 repose sur une architecture découplée.

Mosquitto transporte les événements.

Python assure le traitement.

PostgreSQL assure la persistance.

Grafana assure la visualisation.

Docker simplifie le déploiement et sépare les services.

MQTT
  ↓
Mosquitto
  ↓
Python
  ↓
PostgreSQL
  ↓
Grafana

Cette architecture constitue la base qui permettra ensuite d’ajouter les fonctionnalités de cybersécurité et de résilience de Sentinel.

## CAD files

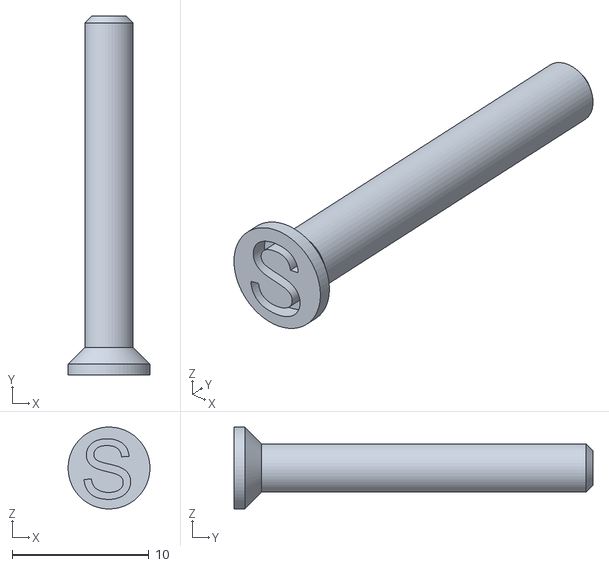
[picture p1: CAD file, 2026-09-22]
B3G6_vis.stl
6.00 x 26.3 x 6.00

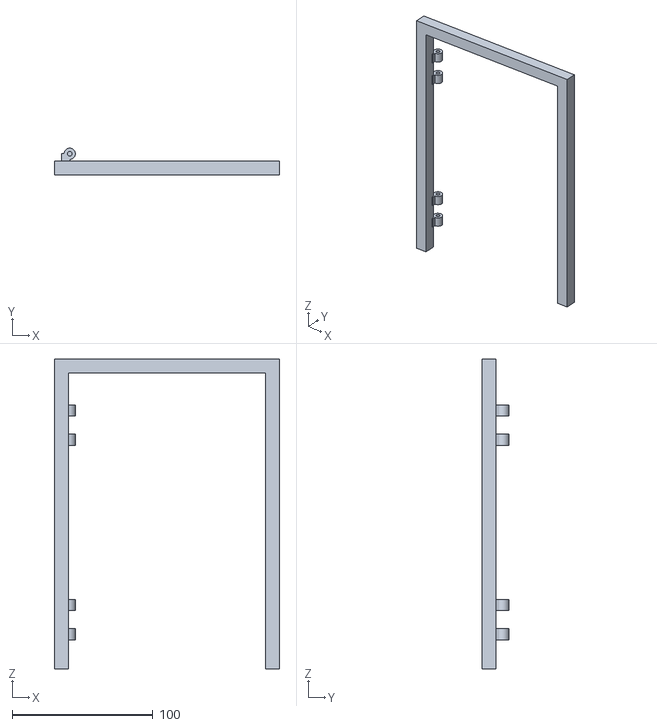
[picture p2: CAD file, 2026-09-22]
B3G6_Encadrement_charnieres.stl
160.0 x 19.0 x 220.0

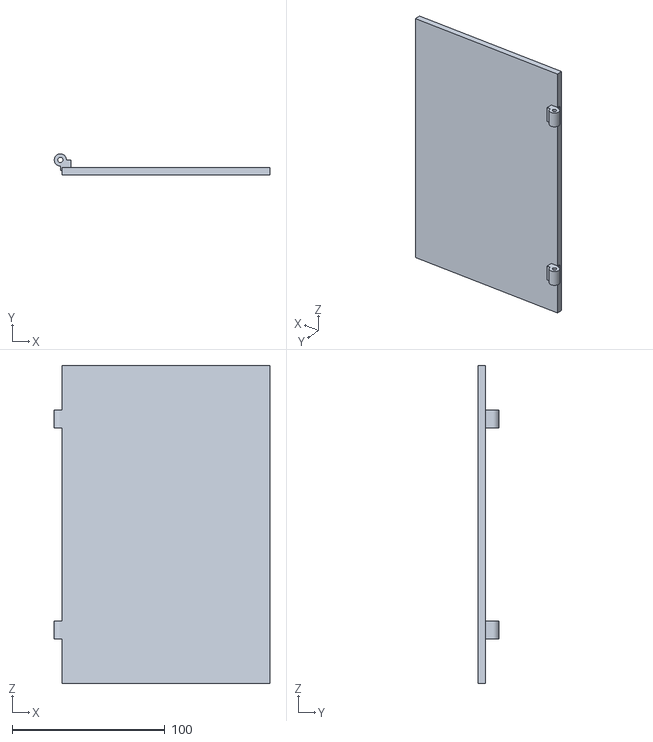
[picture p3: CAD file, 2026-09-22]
B3G6_Porte_mobile_charnieres.stl
141.0 x 14.0 x 208.0

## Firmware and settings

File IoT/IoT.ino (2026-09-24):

#include <SPI.h>
#include <MFRC522.h>
#include <Servo.h>
#include <ESP8266WiFi.h>
#include <PubSubClient.h>

// =====================================================
// WIFI / MQTT
// =====================================================

const char* WIFI_SSID = "S25 de Benjamin";
const char* WIFI_PASSWORD = "passwords";

// METTRE ICI L'IP ACTUELLE DE LA VM DEBIAN
const char* MQTT_SERVER = "10.240.140.182";
const int MQTT_PORT = 1883;

WiFiClient espClient;
PubSubClient mqttClient(espClient);

unsigned long dernierEssaiWifi = 0;
unsigned long dernierEssaiMQTT = 0;


// =====================================================
// RFID
// =====================================================

#define SS_PIN  D8
#define RST_PIN D3

MFRC522 rfid(SS_PIN, RST_PIN);


// =====================================================
// SERVO / BUZZER / CAPTEUR / LED
// =====================================================

const int PIN_SERVO     = D2;
const int PIN_BUZZER    = D1;
const int PIN_MAGNET    = A0;
const int PIN_LED_ROUGE = D4;
const int PIN_LED_VERTE = D0;

const int SEUIL_MAGNET = 512;


// =====================================================
// SERVO
// =====================================================

const int ANGLE_FERME  = 0;
const int ANGLE_OUVERT = 80;

Servo monServo;


// =====================================================
// TEMPORISATIONS
// =====================================================

// Si personne n'ouvre après un badge valide,
// le sas se reverrouille automatiquement.
const unsigned long DELAI_OUVERTURE_MS = 10000;

// Filtrage du capteur magnétique
const unsigned long STABILITE_MS = 150;


// =====================================================
// EQUIPES
// =====================================================

struct Equipe {
  const char* nom;
  byte uid[4];
  bool accesAutorise;
};

Equipe equipes[4] = {
  {"Equipe Securite",    {0x90, 0xE5, 0x2E, 0xA4}, true},
  {"Equipe Medicale",    {0x6B, 0xB0, 0xF1, 0xAE}, true},
  {"Equipe Energetique", {0x5B, 0xDB, 0x75, 0xBD}, false},
  {"Equipe Alimentaire", {0x2E, 0x45, 0xC9, 0x49}, false}
};


// =====================================================
// ETAT DU SAS
// =====================================================

enum EtatAcces {
  REPOS,
  DEVERROUILLE,
  PASSAGE_EN_COURS
};

EtatAcces etatAcces = REPOS;

unsigned long debutAcces = 0;

bool alarmeActive = false;
bool alarmeDejaArretee = false;


// =====================================================
// ETAT DE PORTE POUR MQTT
// =====================================================

bool premierEtatPorte = true;
bool ancienEtatPorteFermee = true;


// =====================================================
// MQTT
// =====================================================

void publierMQTT(const char* topic, const char* message) {

  // Le fonctionnement local du sas continue même si MQTT tombe
  if (!mqttClient.connected()) {
    return;
  }

  mqttClient.publish(topic, message);

  Serial.print("[MQTT] ");
  Serial.print(topic);
  Serial.print(" -> ");
  Serial.println(message);
}


// =====================================================
// WIFI
// =====================================================

void maintenirWifi() {

  if (WiFi.status() == WL_CONNECTED) {
    return;
  }

  // Nouvelle tentative toutes les 5 secondes
  if (millis() - dernierEssaiWifi < 5000) {
    return;
  }

  dernierEssaiWifi = millis();

  Serial.println("[WIFI] Tentative de reconnexion...");

  WiFi.begin(
    WIFI_SSID,
    WIFI_PASSWORD
  );
}


// =====================================================
// CONNEXION MQTT
// =====================================================

void maintenirMQTT() {

  if (WiFi.status() != WL_CONNECTED) {
    return;
  }

  if (mqttClient.connected()) {
    mqttClient.loop();
    return;
  }

  // Nouvelle tentative toutes les 5 secondes
  if (millis() - dernierEssaiMQTT < 5000) {
    return;
  }

  dernierEssaiMQTT = millis();

  Serial.print("[MQTT] Connexion vers ");
  Serial.print(MQTT_SERVER);
  Serial.print(":");
  Serial.println(MQTT_PORT);

  // Last Will :
  // si l'ESP disparaît brutalement, Mosquitto publie "offline"
  bool connexionOK = mqttClient.connect(
    "ESP8266-SAS-A01",

    "sentinel/sas/A01/status",
    0,
    true,
    "offline"
  );

  if (connexionOK) {

    Serial.println("[MQTT] Connecte a Mosquitto");

    // Etat online retenu par Mosquitto
    mqttClient.publish(
      "sentinel/sas/A01/status",
      "online",
      true
    );

    // Envoie immédiatement l'état réel de la porte
    bool porteFermee = lirePorteFermee();

    if (porteFermee) {

      mqttClient.publish(
        "sentinel/sas/A01/porte",
        "fermee"
      );

    } else {

      mqttClient.publish(
        "sentinel/sas/A01/porte",
        "ouverte"
      );
    }

  } else {

    Serial.print("[MQTT] Echec connexion. Code : ");
    Serial.println(mqttClient.state());
  }
}


// =====================================================
// SETUP
// =====================================================

void setup() {

  Serial.begin(115200);

  delay(500);

  Serial.println();
  Serial.println("===============================");
  Serial.println("       SENTINEL - SAS A01");
  Serial.println("===============================");


  // RFID
  SPI.begin();
  rfid.PCD_Init();


  // Servo
  monServo.attach(
    PIN_SERVO,
    500,
    2450
  );


  // Sorties
  pinMode(PIN_BUZZER, OUTPUT);
  pinMode(PIN_LED_ROUGE, OUTPUT);
  pinMode(PIN_LED_VERTE, OUTPUT);

  digitalWrite(PIN_BUZZER, LOW);
  digitalWrite(PIN_LED_ROUGE, LOW);
  digitalWrite(PIN_LED_VERTE, LOW);

  monServo.write(ANGLE_FERME);


  // ===================================================
  // WIFI
  // ===================================================

  WiFi.mode(WIFI_STA);

  WiFi.begin(
    WIFI_SSID,
    WIFI_PASSWORD
  );


  // ===================================================
  // MQTT
  // ===================================================

  mqttClient.setServer(
    MQTT_SERVER,
    MQTT_PORT
  );

  mqttClient.setKeepAlive(30);


  Serial.println("[LOCAL] Systeme du SAS operationnel");
  Serial.println("[WIFI] Connexion en cours...");
  Serial.println("Approchez un badge...");
}


// =====================================================
// LOOP
// =====================================================

void loop() {

  // ===================================================
  // RESEAU
  // ===================================================

  maintenirWifi();
  maintenirMQTT();


  // Affichage IP ESP une seule fois après connexion
  static bool wifiAnnonce = false;

  if (
    WiFi.status() == WL_CONNECTED &&
    !wifiAnnonce
  ) {

    wifiAnnonce = true;

    Serial.println("[WIFI] Connecte");

    Serial.print("[WIFI] IP de l'ESP : ");
    Serial.println(WiFi.localIP());
  }

  if (WiFi.status() != WL_CONNECTED) {
    wifiAnnonce = false;
  }


  // ===================================================
  // CAPTEUR MAGNETIQUE
  // ===================================================

  bool porteFermee = lirePorteFermee();
  bool porteOuverte = !porteFermee;


  // ===================================================
  // ENVOI ETAT PORTE MQTT
  // ===================================================

  if (premierEtatPorte) {

    ancienEtatPorteFermee = porteFermee;
    premierEtatPorte = false;

  }

  else if (
    porteFermee != ancienEtatPorteFermee
  ) {

    ancienEtatPorteFermee = porteFermee;

    if (porteFermee) {

      Serial.println("[PORTE] Fermee");

      publierMQTT(
        "sentinel/sas/A01/porte",
        "fermee"
      );

    } else {

      Serial.println("[PORTE] Ouverte");

      publierMQTT(
        "sentinel/sas/A01/porte",
        "ouverte"
      );
    }
  }


  // ===================================================
  // RFID
  // ===================================================

  if (
    rfid.PICC_IsNewCardPresent() &&
    rfid.PICC_ReadCardSerial()
  ) {

    int index = trouverEquipe();


    // Badge connu
    if (index != -1) {

      Serial.print("[RFID] Badge reconnu : ");
      Serial.println(equipes[index].nom);


      // =================================================
      // BADGE AUTORISE
      // =================================================

      if (equipes[index].accesAutorise) {

        publierMQTT(
          "sentinel/sas/A01/nfc",
          "autorise"
        );

        if (alarmeActive) {

          arreterAlarme(
            equipes[index].nom
          );

        } else {

          accesAutorise(
            equipes[index].nom
          );
        }
      }


      // =================================================
      // BADGE REFUSE
      // =================================================

      else {

        Serial.println(
          "[RFID] Acces refuse"
        );

        publierMQTT(
          "sentinel/sas/A01/nfc",
          "refuse"
        );

        accesRefuse();
      }
    }


    // ===================================================
    // BADGE INCONNU
    // ===================================================

    else {

      Serial.println(
        "[RFID] Badge inconnu"
      );

      publierMQTT(
        "sentinel/sas/A01/nfc",
        "refuse"
      );

      accesRefuse();
    }


    rfid.PICC_HaltA();
    rfid.PCD_StopCrypto1();
  }


  // ===================================================
  // GESTION PASSAGE
  // ===================================================

  gererAcces(porteFermee);


  // ===================================================
  // RESET ALARME
  // ===================================================

  if (porteFermee) {
    alarmeDejaArretee = false;
  }


  // ===================================================
  // DETECTION INTRUSION
  // ===================================================

  if (
    porteOuverte &&
    etatAcces == REPOS &&
    !alarmeActive &&
    !alarmeDejaArretee
  ) {

    declencherAlarme();
  }


  // ===================================================
  // ALARME ACTIVE
  // ===================================================

  if (alarmeActive) {

    digitalWrite(
      PIN_BUZZER,
      HIGH
    );

    digitalWrite(
      PIN_LED_ROUGE,
      HIGH
    );

    delay(80);

    digitalWrite(
      PIN_BUZZER,
      LOW
    );

    digitalWrite(
      PIN_LED_ROUGE,
      LOW
    );

    delay(80);
  }
}


// =====================================================
// CAPTEUR MAGNETIQUE FILTRE
// =====================================================

bool lirePorteFermee() {

  static bool etatStable = true;
  static bool dernierBrut = true;
  static unsigned long vuA = 0;

  bool brut = (
    analogRead(PIN_MAGNET) <
    SEUIL_MAGNET
  );


  if (brut != dernierBrut) {

    dernierBrut = brut;

    vuA = millis();

  }

  else if (
    brut != etatStable &&
    millis() - vuA >= STABILITE_MS
  ) {

    etatStable = brut;
  }

  return etatStable;
}


// =====================================================
// GESTION PASSAGE AUTORISE
// =====================================================

void gererAcces(bool porteFermee) {

  if (etatAcces == REPOS) {
    return;
  }


  // ===================================================
  // PORTE DEVERROUILLEE
  // ===================================================

  if (etatAcces == DEVERROUILLE) {

    // La personne vient d'ouvrir
    if (!porteFermee) {

      Serial.println(
        "[ACCES] Porte ouverte, passage en cours..."
      );

      etatAcces = PASSAGE_EN_COURS;

      return;
    }


    // Personne n'a ouvert après 10 secondes
    if (
      millis() - debutAcces >=
      DELAI_OUVERTURE_MS
    ) {

      verrouiller(
        "personne n'est passe"
      );
    }

    return;
  }


  // ===================================================
  // PASSAGE EN COURS
  // ===================================================

  if (
    etatAcces == PASSAGE_EN_COURS &&
    porteFermee
  ) {

    verrouiller(
      "porte refermee"
    );
  }
}


// =====================================================
// VERROUILLAGE
// =====================================================

void verrouiller(
  const char* raison
) {

  monServo.write(
    ANGLE_FERME
  );

  digitalWrite(
    PIN_LED_VERTE,
    LOW
  );

  etatAcces = REPOS;

  Serial.print(
    "[ACCES] Sas verrouille : "
  );

  Serial.println(
    raison
  );
}


// =====================================================
// RECHERCHE EQUIPE
// =====================================================

int trouverEquipe() {

  if (rfid.uid.size != 4) {
    return -1;
  }

  for (int e = 0; e < 4; e++) {

    bool correspond = true;

    for (
      byte i = 0;
      i < 4;
      i++
    ) {

      if (
        rfid.uid.uidByte[i] !=
        equipes[e].uid[i]
      ) {

        correspond = false;

        break;
      }
    }

    if (correspond) {
      return e;
    }
  }

  return -1;
}


// =====================================================
// ACCES AUTORISE
// =====================================================

void accesAutorise(
  const char* nomEquipe
) {

  Serial.print(
    "[ACCES] Autorise pour : "
  );

  Serial.println(
    nomEquipe
  );


  // MQTT
  // Utile pour identifier l'équipe dans Grafana
  publierMQTT(
    "sentinel/sas/A01/equipe",
    nomEquipe
  );


  digitalWrite(
    PIN_LED_VERTE,
    HIGH
  );

  bipCourt();

  monServo.write(
    ANGLE_OUVERT
  );


  // IMPORTANT :
  // aucun delay(3000) ici.
  // Le programme continue à gérer MQTT et le capteur.
  etatAcces = DEVERROUILLE;

  debutAcces = millis();
}


// =====================================================
// ACCES REFUSE
// =====================================================

void accesRefuse() {

  digitalWrite(
    PIN_LED_ROUGE,
    HIGH
  );

  alarmerefuse();

  digitalWrite(
    PIN_LED_ROUGE,
    LOW
  );
}


// =====================================================
// DECLENCHEMENT ALARME
// =====================================================

void declencherAlarme() {

  Serial.println(
    "[ALARME] Porte forcee sans badge !"
  );

  alarmeActive = true;


  // MQTT -> listener -> PostgreSQL -> Grafana + Telegram
  publierMQTT(
    "sentinel/sas/A01/alarme",
    "intrusion"
  );
}


// =====================================================
// ARRET ALARME
// =====================================================

void arreterAlarme(
  const char* nomEquipe
) {

  Serial.print(
    "[ALARME] Arretee par : "
  );

  Serial.println(
    nomEquipe
  );

  alarmeActive = false;

  alarmeDejaArretee = true;

  digitalWrite(
    PIN_BUZZER,
    LOW
  );

  digitalWrite(
    PIN_LED_ROUGE,
    LOW
  );


  // Information supplémentaire pour la supervision
  publierMQTT(
    "sentinel/sas/A01/alarme_etat",
    "inactive"
  );

  publierMQTT(
    "sentinel/sas/A01/equipe",
    nomEquipe
  );
}


// =====================================================
// BIP COURT
// =====================================================

void bipCourt() {

  digitalWrite(
    PIN_BUZZER,
    HIGH
  );

  delay(150);

  digitalWrite(
    PIN_BUZZER,
    LOW
  );
}


// =====================================================
// ALARME ACCES REFUSE
// =====================================================

void alarmerefuse() {

  for (int i = 0; i < 2; i++) {

    digitalWrite(
      PIN_BUZZER,
      HIGH
    );

    delay(100);

    digitalWrite(
      PIN_BUZZER,
      LOW
    );

    delay(100);
  }
}

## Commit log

2026-09-22 Code ino permettant de controler les accès d'une porte
2026-09-22 Ajout de l'API FastAPI pour le dashboard
2026-09-22 Modélisation Imprimante 3D Porte
    [B3G6_Encadrement_charnieres.stl, B3G6_Porte_mobile_charnieres.stl, B3G6_vis.stl]
2026-09-23 fermeture porte que si aiment detecté
2026-09-23 fix: afficher la cause des erreurs Telegram et nettoyer token/chat_id
    Claude-Session: https://claude.ai/code/session_016DgRGmw2rGi77Eonuui9y6
2026-09-23 feat: l'ESP8266 publie les intrusions en MQTT vers le bot Telegram
    - IoT.ino : connexion Wi-Fi/MQTT non bloquante, publication de
    l'intrusion, de l'arret d'alarme et des badges refuses
    - secrets.h (ignore par git) pour le Wi-Fi et l'IP du broker
    - backend : l'arret d'alarme n'est plus traite comme une intrusion,
    messages Telegram plus lisibles
    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
    [IoT.ino]
2026-09-23 Revert "feat: l'ESP8266 publie les intrusions en MQTT vers le bot Telegram"
    Annule a70d533 a la demande de l'utilisateur.
    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
    [IoT.ino]
2026-09-23 Dashboard : Dockerfile et adresse de l'API en variable
2026-09-24 feat: remonter le nom des equipes lors des scans de badge
    - IoT.ino : connexion Wi-Fi/MQTT non bloquante, chaque scan publie
    accepte:<equipe> ou refuse:<equipe> sur sentinel/sas/nfc
    - mqtt_listener : nouvelle colonne equipe (creee automatiquement)
    - api : champ badge et message renseignes avec l'equipe
    - README : requetes Grafana par equipe
    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
2026-09-24 Revert: retrait du nom des equipes dans les scans de badge
    Annule, a la demande de l'utilisateur, l'ajout du nom des equipes
    (commits 3dcd5d4 et b706117) :
    - IoT.ino revient a la version 2fa2c5a (autorise / refuse)
    - listener et API sans colonne equipe
    - README / CONFIG.md sans la section correspondante
    Les notifications Telegram sont conservees.
    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
    [IoT.ino]
2026-09-24 Revert: annulation de la PR #1 et du commit a87fde2
    Remet main exactement dans l'etat d'avant le merge de la PR #1
    (commit 9df2231), a la demande de l'utilisateur : retrait des
    notifications Telegram et du nom des equipes.
    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
